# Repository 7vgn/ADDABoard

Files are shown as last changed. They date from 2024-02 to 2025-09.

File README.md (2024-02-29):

# AD/DA Board evolved
## An Add-On for the ATmega644(A) Evaluation Board

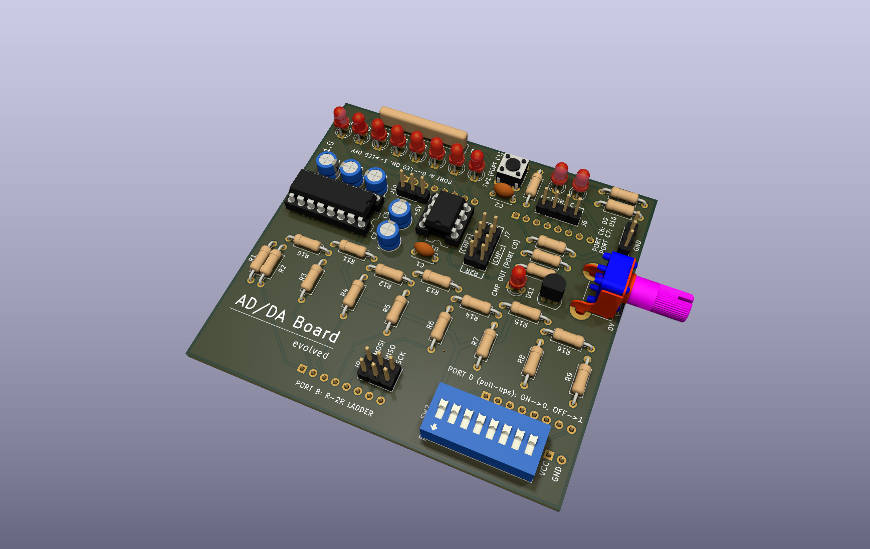
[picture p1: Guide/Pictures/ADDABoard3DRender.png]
3D render of the add-on board


This is an add-on for the [EvaBoard evolved](https://github.com/7vgn/EvaBoard/) ATmega644(A) evaluation board. It is inspired by (and compatible with) the add-on board used in the lab course "Praktikum Systemprogrammierung" in the computer science curriculum at RWTH Aachen. It can be used both with the original [evaluation board](https://www.embedded.rwth-aachen.de/doku.php?id=lehre:atmegaevaboard) and its remake. 

This repository contains:

- A richly illustrated [Guide Book](Guide/ADDABoardGuide.pdf) with everything you need to know to build and use the board
- A [KiCAD project](KiCAD/) with the [Schematic](KiCAD/Schematic.pdf) and a PCB layout, ready to be manufactured
- The [bill of materials](BOM/BOM.pdf)
- [Test code](Tests/) for testing and debugging the board

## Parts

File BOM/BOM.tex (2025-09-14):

\documentclass{article}
\usepackage[a4paper, landscape, margin=2.5cm]{geometry}
\usepackage{multirow}
\usepackage{longtable}
\usepackage{textgreek}
\usepackage{hyperref}

\setlength\parindent{0pt}

\begin{document}
\pagestyle{empty}
\section*{AD/DA Board evolved -- Bill of Materials}
Please read the \href{../Guide/ADDABoardGuide.pdf}{guide book} before ordering. 
The table below lists the codes for ordering the components from \href{https://reichelt.de/}{Reichelt}. 
~\\

\begin{center}
\begin{longtable}{|l|l|l|l|l|}
\hline
\textbf{Reference}&\textbf{Part}&\textbf{Value}&\textbf{Quantity}&\textbf{Reichelt\#}\cr\hline
C1, C2&Ceramic Capacitor&100nF&2&X7R-5 100N\cr\hline
C3..C7&Electrolytic Capacitor&1\textmu F, 63V, radial&5&RAD 1/63\footnote{You can also use tantalum capacitors (TANTAL 1,0/35). These are smaller and recommended by the MAX232 datasheet, but more expensive.}\cr\hline
D1..D8&LED&3mm, red&8&LED 3MM RT\cr\hline
D9, D10&LED&3mm, green&2&LED 3MM GN\cr\hline
D11&LED&3mm, yellow&1&LED 3MM GE\cr\hline
J1&Pin socket&2.54mm, 1x2&1&MPE 094-1-002\cr\hline
J2..J5&Pin socket&2.54mm, 1x8&4&MPE 094-1-008\cr\hline
J6, J8, J10&Pin header&2.54mm, 1 row, 10 total&1&SL 1X36G 2,54\cr\hline
J7, J9&Pin header&2.54mm, 2 rows, 7 total&1&SL 2X36G 2,54\cr\hline
Q1&N-FET Transistor&2N7000&1&2N 7000\cr\hline
R1..R9&Resistor&2k\textOmega&9&METALL 2,00K\cr\hline
R10..R16&Resistor&1k\textOmega&7&METALL 1,00K\cr\hline
R17..R19&Resistor&1.5k\textOmega&3&METALL 1,50K\cr\hline
R20&Resistor&10k\textOmega&1&METALL 10,0K\cr\hline
R21&Resistor&330\textOmega&1&METALL 330\cr\hline
R22&Potentiometer\footnote{Optional. You can use an external variable voltage source instead.}&10k\textOmega&1&RK09K111-LIN10K\cr\hline
R23&Resistor&3.3k\textOmega&1&METALL 3,30K\cr\hline
RN1&Resistor network&8x 1.5k\textOmega&1&SIL 9-8 1,5K\cr\hline
SW1&Pushbutton switch&SPST&1&TASTER 9308\cr\hline
\multirow{2}{*}{U1}&Comparator&LM393&1&LM 393 DIP\cr\cline{2-5}
&IC Socket&2x4, 7.62mm&1&GS 8P\cr\hline
\multirow{2}{*}{U2}&RS-232 transceiver\footnote{Optional. You can ``borrow'' the MAX232 from the evaluation board or connect an external voltage source. See \href{../Guide/ADDABoardGuide.pdf}{guide book} for details.}&MAX232&1&TS232CPE\cr\cline{2-5}
&IC Socket&2x8, 7.62mm&1&GS 16P\cr\hline
\end{longtable}
\end{center}

\end{document}

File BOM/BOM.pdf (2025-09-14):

## AD/DA Board evolved – Bill of Materials

Please read the guide book before ordering. The table below lists the codes for ordering the components from Reichelt. (https://reichelt.de/)

Reference | Part | Value | Quantity | Reichelt#
C1, C2 | Ceramic Capacitor | 100nF | 2 | X7R-5 100N
C3..C7 | Electrolytic Capacitor | 1µF, 63V, radial | 5 | RAD 1/63¹
D1..D8 | LED | 3mm, red | 8 | LED 3MM RT
D9, D10 | LED | 3mm, green | 2 | LED 3MM GN
D11 | LED | 3mm, yellow | 1 | LED 3MM GE
J1 | Pin socket | 2.54mm, 1x2 | 1 | MPE 094-1-002
J2..J5 | Pin socket | 2.54mm, 1x8 | 4 | MPE 094-1-008
J6, J8, J10 | Pin header | 2.54mm, 1 row, 10 total | 1 | SL 1X36G 2,54
J7, J9 | Pin header | 2.54mm, 2 rows, 7 total | 1 | SL 2X36G 2,54
Q1 | N-FET Transistor | 2N7000 | 1 | 2N 7000
R1..R9 | Resistor | 2kΩ | 9 | METALL 2,00K
R10..R16 | Resistor | 1kΩ | 7 | METALL 1,00K
R17..R19 | Resistor | 1.5kΩ | 3 | METALL 1,50K
R20 | Resistor | 10kΩ | 1 | METALL 10,0K
R21 | Resistor | 330Ω | 1 | METALL 330
R22 | Potentiometer² | 10kΩ | 1 | RK09K111-LIN10K
R23 | Resistor | 3.3kΩ | 1 | METALL 3,30K
RN1 | Resistor network | 8x 1.5kΩ | 1 | SIL 9-8 1,5K
SW1 | Pushbutton switch | SPST | 1 | TASTER 9308
U1 | Comparator | LM393 | 1 | LM 393 DIP
| IC Socket | 2x4, 7.62mm | 1 | GS 8P
U2 | RS-232 transceiver³ | MAX232 | 1 | TS232CPE
| IC Socket | 2x8, 7.62mm | 1 | GS 16P

1You can also use tantalum capacitors (TANTAL 1,0/35). These are smaller and recommended by the MAX232 datasheet, but more expensive. 2Optional. You can use an external variable voltage source instead.
3Optional. You can “borrow” the MAX232 from the evaluation board or connect an external voltage source. See guide book for details.

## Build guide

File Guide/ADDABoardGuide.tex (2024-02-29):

\documentclass{article}
\usepackage[a4paper]{geometry}
\usepackage[skip=10pt]{parskip}
\usepackage{graphicx}
\usepackage{hyperref}
\usepackage[section]{placeins}
\usepackage[official]{eurosym}
\usepackage{textgreek}
\usepackage{tcolorbox}
\usepackage{listings}
\usepackage{textcomp}
\usepackage{multirow}
\usepackage{tikz}

\setlength\parindent{0pt}

\newenvironment{note}{\begin{tcolorbox}[colback=blue!5!white,colframe=blue!75!black,title=\textbf{Note}]}{\end{tcolorbox}}
\newenvironment{caution}{\begin{tcolorbox}[colback=red!5!white,colframe=red!75!black,title=\textbf{Caution}]}{\end{tcolorbox}}
\newcommand{\datasheet}{\href{https://ww1.microchip.com/downloads/en/DeviceDoc/doc2593.pdf}{datasheet}}
\newcommand{\file}[1]{\texttt{#1}}
\newcommand{\evaboard}{\href{https://github.com/7vgn/EvaBoard/}{evaluation board}}

\lstset
{
	basicstyle=\footnotesize\ttfamily,
	breaklines=true,
	keywordstyle=\bfseries\color{green!40!black},
	commentstyle=\itshape\color{purple!40!black},
	identifierstyle=\color{blue},
	stringstyle=\color{orange},
	tabsize=4
}

\begin{document}
\hypersetup{pageanchor=false}
\begin{titlepage}
\thispagestyle{empty}
\centering
\textsf{\Huge Guide Book}\\[1cm]
\textsf{\Large For the AD/DA Add-On Board}\\[3cm]

\end{titlepage}
\hypersetup{pageanchor=true}

\tableofcontents
\section{Introduction}
This is an add-on for the ATmega644(A) \evaboard. It is inspired by (and compatible with) the \href{https://www.embedded.rwth-aachen.de/doku.php?id=lehre:atmegaevaboard}{add-on board} used in the lab course "Praktikum Systemprogrammierung" in the computer science curriculum at RWTH Aachen. 

The university encourages students and educators to build the evaluation board themselves. However, no resources for the AD/DA add-on board are provided. 

This project is a complete remake of the original add-on board with a focus on low cost and a non-lab environment (no bench supply etc.). It also includes a ton of documentation, especially for students who have not worked with electronics before. 

\begin{note}
Before reading this, you should familiarize yourself with the \evaboard. Many things from its documentation apply here as well and this document can only be considered complete in conjunction with the \href{../../EvaBoard/Guide/EvaBoardGuide.pdf}{evaluation board's Guide Book}.
\end{note}

\subsection{Getting to Know the Add-On Board}\label{sec:boardOverview}
This add-on board carries multiple components that can be used separately or wired together to create an AD converter:
\begin{itemize}
\item A digital-to-analogue (DA) converter in the shape of an R-2R ladder
\item A comparator with multiple power supply options
\item A potentiometer to create analogue voltages
\item 10 LEDs, a button, and an 8-bit DIP switch
\end{itemize}

For more details, refer to the \href{../KiCAD/Schematic.pdf}{schematic}. 

The add-on board plugs into connectors J11..J14 (Port A..D) and J4 (power) of the evaluation board. Table \ref{tab:connections} shows the connections between the ATmega and the add-on components when the add-on board is mounted. 
\begin{table}
\centering
\begin{tabular}{l|l|l}
\textbf{ATmega644}&\textbf{AD/DA add-on board}&\textbf{Remarks}\cr\hline
Pin A0..A7&LEDs 1..8&active low\cr\hline
Pin B0..B7&R-2R ladder&Pin B7 is the MSB\cr\hline
Pin C0&Comparator output&LED11 also shows the comparator output\cr\hline
Pin C1&Button SW1&pull-up on Pin C1 must be enabled\cr\hline
Pin C2..C5&passed through to J6&not usable while JTAG programming\cr\hline
Pin C6, C7&LEDs 9 and 10&active low\cr\hline
Pin D0..D7&8-bit DIP switch&pull-ups on Port D must be enabled\cr\hline
\end{tabular}
\caption{Connections between the Add-On Board and the Evaluation Board}
\label{tab:connections}
\end{table}

\subsubsection{R-2R Ladder}
An \href{https://en.wikipedia.org/wiki/Resistor_ladder}{R-2R ladder} is a simple circuit that converts a digital value to an analogue voltage using a network of resistors with two different values, one twice as large as the other (1k\textOmega{} and 2k\textOmega{} in our case). 
The R-2R ladder is connected to Port B in such a way that a digital value written to the 8-bit PORTB register is translated proportionally to a voltage between 0V and 5V. The output voltage is available on two pins of J7. 

\begin{note}
Pins 5..7 of Port B are also used for ISP programming. The R-2R ladder will act as a pull-down resistor on these pins. Decent ISP programmers should not have an issue with this. If you encounter difficulties, remove the add-on board while programming or cut the solder jumpers JP1..JP3. You can reconnect these pins to the R-2R ladder by placing jumpers on J9. 
\end{note}

\subsubsection{Comparator}\label{sec:cmp}
The \href{https://www.ti.com/lit/ds/symlink/lm393.pdf}{LM393} is a very common dual comparator. On this board, only one of the two comparators is in use. The comparator has two inputs \texttt{IN+} and \texttt{IN-} and one output. The output is high (logic 1) whenever the voltage at \texttt{IN+} is greater than the voltage at \texttt{IN-}, and low (logic 0) whenever the opposite is the case. The two inputs are available at the middle pins of J7. The output is connected to Port C0 as well as LED11 (``CMP OUT''). 

Figure \ref{fig:cmpSchematic} shows the schematic symbol of a comparator. It resembles that of an operational amplifier. This is not a coincidence: OpAmps can be used as comparators (with mediocre performance). 

\begin{figure}[htb]
\centering
\begin{tikzpicture}
\node[circle,fill,minimum size=6pt,inner sep=0,outer sep=0,label=left:IN+] (INP) at (-1,1) {};
\node[circle,fill,minimum size=6pt,inner sep=0,outer sep=0,label=left:IN-] (INM) at (-1,-1) {};
\node[circle,fill,minimum size=6pt,inner sep=0,outer sep=0,label=right:OUT] (OUT) at (5,0) {};
\node[circle,fill,minimum size=6pt,inner sep=0,outer sep=0,label=right:V+] (VP) at (2,2) {};
\node[circle,fill,minimum size=6pt,inner sep=0,outer sep=0,label=right:V- (GND)] (VM) at (2,-2) {};

\filldraw[fill=yellow!50!white] (0,2) -- (0,-2) -- (4,0) -- cycle;
\draw (INP) -- (0,1);
\draw (INM) -- (0,-1);
\draw (4,0) -- (OUT);
\draw (VP) -- (2,1);
\draw (VM) -- (2,-1);
\end{tikzpicture}
\caption{Comparator Schematic}
\label{fig:cmpSchematic}
\end{figure}

The comparator needs a supply voltage which has to be at least 2V higher than the \texttt{IN+} and \texttt{IN-} voltages (see Section 6.2 in the \href{https://www.ti.com/lit/ds/symlink/lm393.pdf}{datasheet}). Since we want to compare voltages in the 0V..5V range, the comparator must be supplied with at least 7V which is not immediately available on the evaluation board. There are three options:

\begin{itemize}
\item Provide an external supply voltage $\ge$7V between V+ (the middle pin of J10) and GND (J8). Depending on the quality of the external supply, this can be the most stable solution and provide the most accurate results. 
\item Use 5V as the power supply by connecting the middle and bottom pin of J10 with a jumper. This limits the usable range of the comparator to 0V..3V!
\item Create a higher voltage from 5V. Fortunately, the comparator does not draw a lot of current. Thus we can (ab)use a MAX232 driver which creates a voltage somewhere between 8V and 9V, depending on current. You don't even need to buy a MAX232 -- you can pinch the one from the evaluation board, unless you want to use the serial connection and the AD/DA add-on board at the same time. Insert the MAX232 into the U2 socket of the add-on board and connect the middle and top pin of J10 with a jumper. 
\end{itemize}

The third option is recommended since it is cheap while still delivering good results. Figure \ref{fig:cmpSupplyOptions} shows the role of J10 in choosing the comparator supply voltage. 
\begin{figure}[htb]
\centering
\begin{tikzpicture}
\node[circle,fill,minimum size=6pt,inner sep=0,outer sep=0,label=left:8..9V from MAX232] (MAX) at (0,3) {};
\node[circle,fill,minimum size=6pt,inner sep=0,outer sep=0,label=left:$\ge$7V external voltage] (EXT) at (0,2) {};
\node[circle,fill,minimum size=6pt,inner sep=0,outer sep=0,label=left:5V from VCC] (VCC) at (0,1) {};
\node[circle,fill,minimum size=6pt,inner sep=0,outer sep=0,label=right:V+ comparator supply] (VP) at (6,2) {};

\draw (2,0) rectangle (4,4);
\node[anchor=north west] at (4,0) {J10};
\node[circle,fill,minimum size=6pt,inner sep=0,outer sep=0,label=above right:1] (J1) at (3,1) {};
\node[circle,fill,minimum size=6pt,inner sep=0,outer sep=0,label=above right:2] (J2) at (3,2) {};
\node[circle,fill,minimum size=6pt,inner sep=0,outer sep=0,label=above right:3] (J3) at (3,3) {};

\draw (MAX) -- (J3);
\draw (VCC) -- (J1);
\draw[dashed] (EXT) -- (J2);
\draw (J2) -- (VP);

\draw[draw=blue] (2.45,0.5) rectangle (3.45,2.5);
\draw[draw=green!70!black] (2.55,1.5) rectangle (3.55,3.5);
\end{tikzpicture}
\caption{Comparator Supply Voltage Options}
\label{fig:cmpSupplyOptions}
\end{figure}

\subsubsection{Potentiometer}\label{sec:poti}
Since the whole purpose of an AD converter is to measure some analogue voltage, we need a way of generating one. The potentiometer R22 acts as a variable voltage divider between 5V and GND. When turned all the way to the left, its output is 0V, to the right it's 5V. The potentiometer output is available on two pins of J7. If you have a variable external voltage source available, you can of course omit R22. 

\subsection{Changes from the Original Board}\label{sec:differences}
No schematic is published for the original AD/DA board. Figure \ref{fig:addaOrig} is our best guess of what it looks like. 

\begin{figure}[htb]
\centering

\caption{Schematic of the Original AD/DA Add-on Board (guesswork)}
\label{fig:addaOrig}
\end{figure}

The main difference is the use of the LM393 comparator instead of an LM358 OpAmp and its power supply. Re-using the MAX232 instead of two additional voltage regulators lowers the cost of this board significantly. 

\section{Building the Board}
Please read the corresponding chapter in the evaluation board's \href{https://github.com/7vgn/EvaBoard/Guide/EvaBoardGuide.pdf}{guide book}. Assembling the add-on board should not pose any additional difficulties. 

\begin{note}
The best technique for soldering the pin sockets J1..J5 onto the back of the PCB is to attach them to the (unpowered!) evaluation board, then place the add-on PCB on top and solder all pins. This way, the add-on board will fit perfectly onto the evaluation board. 
\end{note}

\begin{caution}
Make sure to cut all the components' legs short enough so they won't touch anything on the evaluation board. To be safe, cover the back of the add-on board with tape. 
\end{caution}

\subsection{Optional Components}
The potentiometer R22 can be omitted in favour of an external variable voltage source, see Section \ref{sec:poti}. 

If the ATmega is programmed exclusively via JTAG, J6 is unnecessary since those pins aren't usable anyway. 

J9 can be left unpopulated unless you need to cut the solder jumpers JP1..3 due to problems with ISP programming while the R-2R ladder is connected to Port B. 

The IC socket for U2 as well as C3..C7 can be omitted if you are providing the comparator with a different supply voltage, see Section \ref{sec:cmp}. 

If you are using tantalum capacitors for C3..C7, make sure to get the polarity correct. Unfortunately, the markings are not uniform. The plus side might be marked by a plus sign, a line, a dot, or a longer leg. If there is text printed on it, the plus side is usually on the right. If in doubt, \href{https://en.wikipedia.org/wiki/Tantalum_capacitor#Polarity_marking}{read up} on it before soldering -- with the wrong polarity tantalum capacitors can explode!

\section{Testing}
The test programs can be found in the \href{../Tests/}{\file{Tests/} subdirectory} of this repository. They all come with makefiles for AVR-GCC and AVRDUDE. Alternatively, you can create a project in your IDE of choice and import the source files there. Be sure to define the \lstinline[language=C]{F_CPU} constant if your IDE doesn't do that automatically.

\subsection{DIP switches and LEDs}
The code for this test can be found in \href{../Tests/DIPLED/}{\file{Tests/DIPLED/}}. 

\paragraph{Preparation}
Plug the AD/DA add-on board onto the evaluation board. 

\paragraph{Expected Result}
Whenever a DIP switch is activated, the corresponding LED should light up. Pressing the SW1 should switch between LED9 and LED10. 

\begin{figure}[htb]
\centering
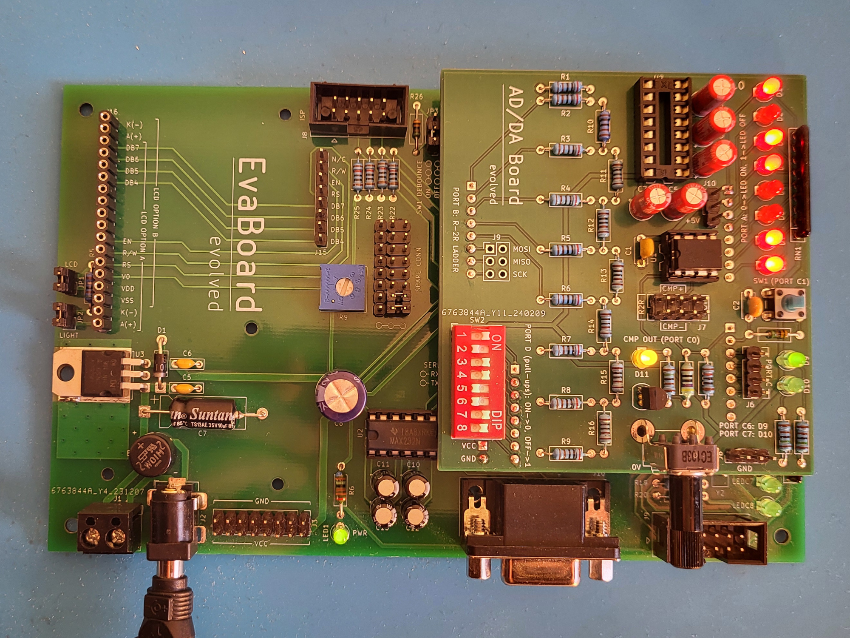
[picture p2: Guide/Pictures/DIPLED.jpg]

\caption{Setup for Testing the DIP Switches and LEDs}
\label{fig:dipLed}
\end{figure}

\paragraph{Troubleshooting}
Make sure the evaluation board works reliably. After that, any failure on this simple test is probably due to bad soldering or an LED being placed the wrong way. 

\subsection{R-2R Ladder}
The code for this test can be found in \href{../Tests/R2R/}{\file{Tests/R2R/}}. This test requires a somewhat accurate multimeter. 

\paragraph{Preparation}
Plug the AD/DA add-on board onto the evaluation board. 

\paragraph{Expected Result}
Enter a value $v\in\{0,\ldots,255\}$ in binary via the DIP switches. It should be echoed on the LEDs. Measure the voltage $U$ between the R2R pins on J7 and GND (J8). You should get approximately the following relation:
\[
U=5V\cdot\frac{v}{255}
\]
For a more precise result, measure the supply voltage (pin marked ``+5V'' on J10) and replace the ``5V'' in the equation with that value. 

\paragraph{Troubleshooting}
If the observed values deviate significantly from the expected ones, check if you have chosen the correct values for all resistors. You might also have a bad solder joint on one of the resistors, adding a few ohms. 

\begin{note}
When one of the ATmega's output pins is set to logic 1, its voltage does not quite reach VCC\footnote{The \href{https://ww1.microchip.com/downloads/en/DeviceDoc/doc2593.pdf}{datasheet} guarantees 4.2V, see Section 26.2. The exact value depends on the current sourced from the pin, see Figure 27-31.}. Therefore, the observed values will probably all have a slight downward bias. 
\end{note}

\subsection{A Primitive AD converter}
The code for this test can be found in \href{../Tests/ADC/}{\file{Tests/ADC/}}. 

\paragraph{Preparation}
Plug the AD/DA add-on board onto the evaluation board. Connect R-2R to CMP+ and POT to CMP- by placing two jumpers on J7. 
Use one of the methods from Section \ref{sec:cmp} to supply the comparator with voltage. 

\begin{figure}[htb]
\centering
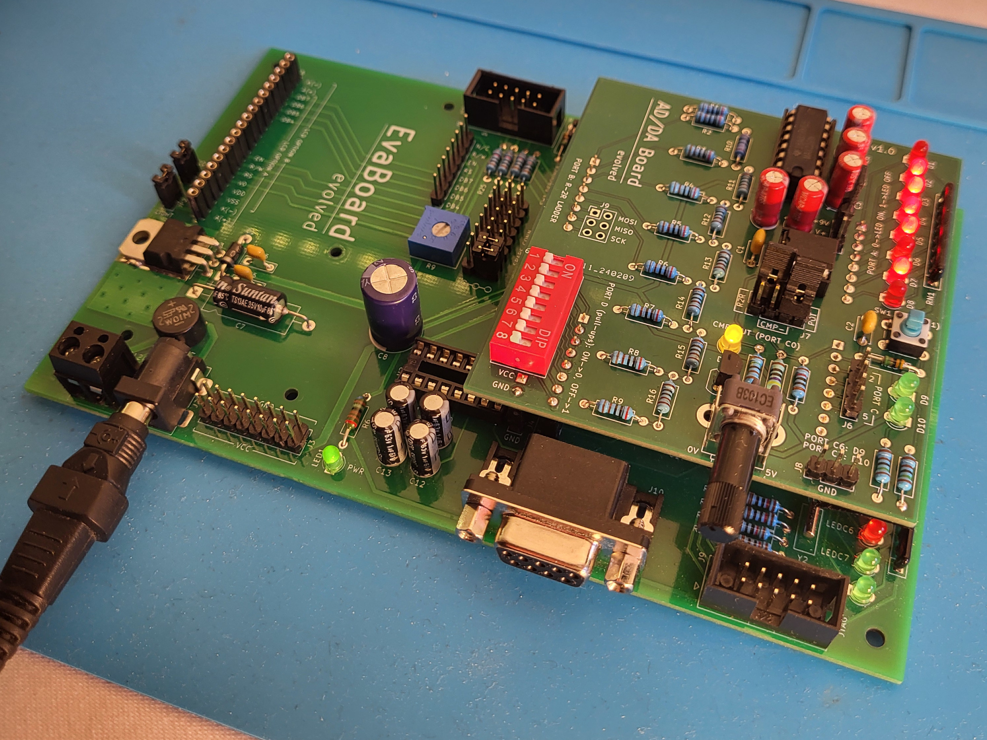
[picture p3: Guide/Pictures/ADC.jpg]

\caption{Setup for a Simple AD Converter (Using MAX232 for Supplying the Comparator)}
\label{fig:adc}
\end{figure}

\paragraph{Expected Result}
Select a voltage with the potentionmeter. Press the RESET button or disconnect and re-connect the power or reset the microcontroller via the programmer. 

The LEDs should show an increasing binary value which stops when the corresponding voltage from the R-2R ladder exceeds the potentiometer voltage. This is indicated by the ``CMP OUT'' LED lighting up. 

\begin{note}
This is a very primitive and slow ADC. You might view it as a linear search for the value where the comparator first outputs 1. You can improve it massively by using a more sophisticated search algorithm. 
\end{note}

\section{Known Issues}
In theory, the LEDs 1..10 and SW1 are superfluous. One could save on parts and use the LEDs and buttons on the evaluation board instead. However, this would require the PCB to be non-rectangular, probably offsetting any savings. 

\section{Version History}
\begin{description}
\item[v1.0] Initial release
\end{description}

\end{document}

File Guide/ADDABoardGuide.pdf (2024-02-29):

# Guide Book

## For the AD/DA Add-On Board


## Contents

1 Introduction | 1
2 Building the Board | 4
3 Testing | 5
4 Known Issues | 8
5 Version History | 8

## 1 Introduction

This is an add-on for the ATmega644(A) evaluation board. (https://github.com/jdcr0/EvaBoard/) It is inspired by (and compatible with) the add-on board (https://www.embedded.rwth-aachen.de/doku.php?id=lehre:atmegaevaboard) used in the lab course ”Praktikum Systemprogrammierung” in the computer science curriculum at RWTH Aachen.

The university encourages students and educators to build the evaluation board themselves. However, no resources for the AD/DA add-on board are provided.

This project is a complete remake of the original add-on board with a focus on low cost and a non-lab environment (no bench supply etc.). It also includes a ton of documentation, especially for students who have not worked with electronics before.

Note

Before reading this, you should familiarize yourself with the evaluation board. (https://github.com/jdcr0/EvaBoard/) Many things from its documentation apply here as well and this document can only be considered complete in conjunction with the evaluation board’s Guide Book.

### 1.1 Getting to Know the Add-On Board

This add-on board carries multiple components that can be used separately or wired together to create an AD converter:

- A digital-to-analogue (DA) converter in the shape of an R-2R ladder
- A comparator with multiple power supply options
- A potentiometer to create analogue voltages

1

ATmega644 | AD/DA add-on board | Remarks
Pin A0..A7 | LEDs 1..8 | active low
Pin B0..B7 | R-2R ladder | Pin B7 is the MSB
Pin C0 | Comparator output | LED11 also shows the comparator output
Pin C1 | Button SW1 | pull-up on Pin C1 must be enabled
Pin C2..C5 | passed through to J6 | not usable while JTAG programming
Pin C6, C7 | LEDs 9 and 10 | active low
Pin D0..D7 | 8-bit DIP switch | pull-ups on Port D must be enabled

Table 1: Connections between the Add-On Board and the Evaluation Board

- 10 LEDs, a button, and an 8-bit DIP switch

For more details, refer to the schematic.

The add-on board plugs into connectors J11..J14 (Port A..D) and J4 (power) of the evaluation board. Table 1 shows the connections between the ATmega and the add-on components when the add-on board is mounted.

### 1.1.1 R-2R Ladder

An R-2R ladder (https://en.wikipedia.org/wiki/Resistor_ladder) is a simple circuit that converts a digital value to an analogue voltage using a network of resistors with two different values, one twice as large as the other (1kΩ and 2kΩ in our case). The R-2R ladder is connected to Port B in such a way that a digital value written to the 8-bit PORTB register is translated proportionally to a voltage between 0V and 5V. The output voltage is available on two pins of J7.

Note

Pins 5..7 of Port B are also used for ISP programming. The R-2R ladder will act as a pull-down resistor on these pins. Decent ISP programmers should not have an issue with this. If you encounter difficulties, remove the add-on board while programming or cut the solder jumpers JP1..JP3. You can reconnect these pins to the R-2R ladder by placing jumpers on J9.

### 1.1.2 Comparator

The LM393 (https://www.ti.com/lit/ds/symlink/lm393.pdf) is a very common dual comparator. On this board, only one of the two comparators is in use. The comparator has two inputs IN+ and IN- and one output. The output is high (logic
1) whenever the voltage at IN+ is greater than the voltage at IN-, and low (logic 0) whenever the opposite is the case. The two inputs are available at the middle pins of J7. The output is connected to Port C0 as well as LED11 (“CMP OUT”).

Figure 1 shows the schematic symbol of a comparator. It resembles that of an operational amplifier. This is not a coincidence: OpAmps can be used as comparators (with mediocre performance).

The comparator needs a supply voltage which has to be at least 2V higher than the IN+ and IN-voltages (see Section 6.2 in the datasheet). (https://www.ti.com/lit/ds/symlink/lm393.pdf) Since we want to compare voltages in the 0V..5V

2

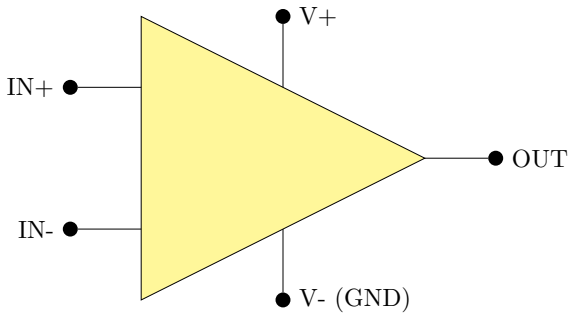
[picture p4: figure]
OUT; V- (GND)

Figure 1: Comparator Schematic

range, the comparator must be supplied with at least 7V which is not immediately available on the evaluation board. There are three options:

- Provide an external supply voltage ≥7V between V+ (the middle pin of J10) and GND (J8). Depending on the quality of the external supply, this can be the most stable solution and provide the most accurate results.
- Use 5V as the power supply by connecting the middle and bottom pin of J10 with a jumper. This limits the usable range of the comparator to 0V..3V!
- Create a higher voltage from 5V. Fortunately, the comparator does not draw a lot of current. Thus we can (ab)use a MAX232 driver which creates a voltage somewhere between 8V and 9V, depending on current. You don’t even need to buy a MAX232 – you can pinch the one from the evaluation board, unless you want to use the serial connection and the AD/DA add-on board at the same time. Insert the MAX232 into the U2 socket of the add-on board and connect the middle and top pin of J10 with a jumper.

The third option is recommended since it is cheap while still delivering good results. Figure 2 shows the role of J10 in choosing the comparator supply voltage.

8..9V from MAX232

≥7V external voltage

5V from VCC

V+ comparator supply

J10

1

2

3

Figure 2: Comparator Supply Voltage Options

3

### 1.1.3 Potentiometer

Since the whole purpose of an AD converter is to measure some analogue voltage, we need a way of generating one. The potentiometer R22 acts as a variable voltage divider between 5V and GND. When turned all the way to the left, its output is 0V, to the right it’s 5V. The potentiometer output is available on two pins of J7. If you have a variable external voltage source available, you can of course omit R22.

### 1.2 Changes from the Original Board

No schematic is published for the original AD/DA board. Figure 3 is our best guess of what it

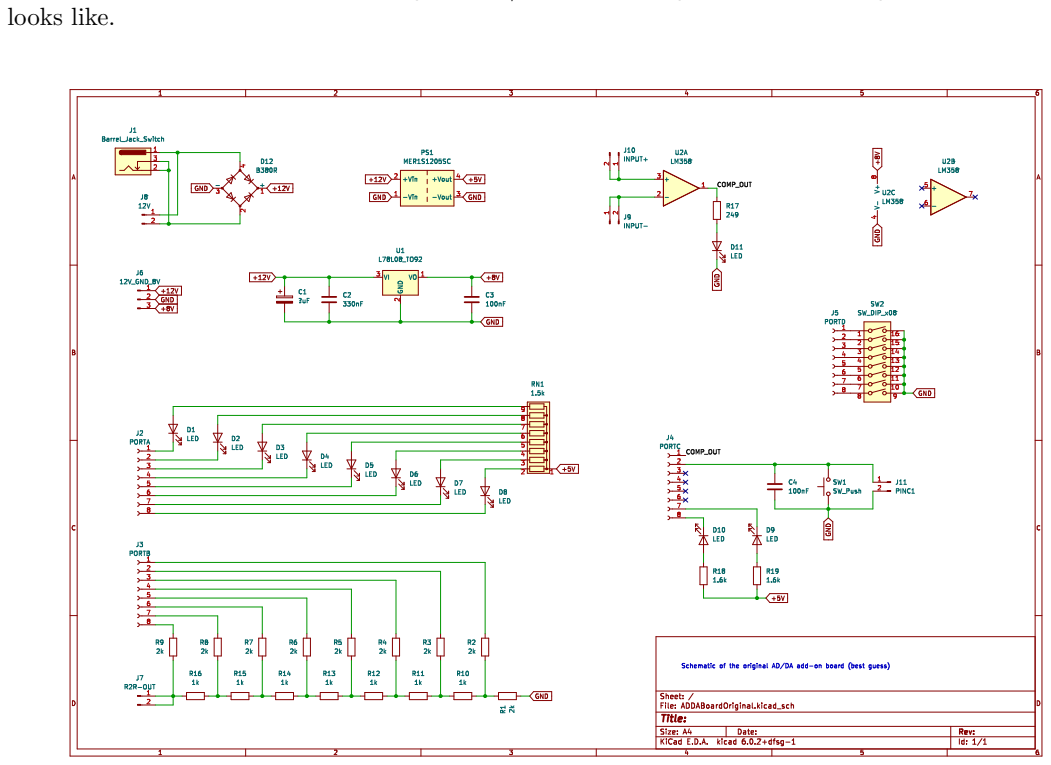
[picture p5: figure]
looks like.

Figure 3: Schematic of the Original AD/DA Add-on Board (guesswork)

The main difference is the use of the LM393 comparator instead of an LM358 OpAmp and its power supply. Re-using the MAX232 instead of two additional voltage regulators lowers the cost of this board significantly.

## 2 Building the Board

Please read the corresponding chapter in the evaluation board’s guide book. (https://github.com/jdcr0/EvaBoard/Guide/EvaBoardGuide.pdf) Assembling the add-on board should not pose any additional difficulties.

4

Note

The best technique for soldering the pin sockets J1..J5 onto the back of the PCB is to attach them to the (unpowered!) evaluation board, then place the add-on PCB on top and solder all pins. This way, the add-on board will fit perfectly onto the evaluation board.

Caution

Make sure to cut all the components’ legs short enough so they won’t touch anything on the evaluation board. To be safe, cover the back of the add-on board with tape.

### 2.1 Optional Components

The potentiometer R22 can be omitted in favour of an external variable voltage source, see Section 1.1.3.

If the ATmega is programmed exclusively via JTAG, J6 is unnecessary since those pins aren’t usable anyway.

J9 can be left unpopulated unless you need to cut the solder jumpers JP1..3 due to problems with ISP programming while the R-2R ladder is connected to Port B.

The IC socket for U2 as well as C3..C7 can be omitted if you are providing the comparator with a different supply voltage, see Section 1.1.2.

If you are using tantalum capacitors for C3..C7, make sure to get the polarity correct. Unfor-tunately, the markings are not uniform. The plus side might be marked by a plus sign, a line, a dot, or a longer leg. If there is text printed on it, the plus side is usually on the right. If in doubt, read up (https://en.wikipedia.org/wiki/Tantalum_capacitor#Polarity_marking) on it before soldering – with the wrong polarity tantalum capacitors can explode!

## 3 Testing

The test programs can be found in the Tests/ subdirectory of this repository. They all come with makefiles for AVR-GCC and AVRDUDE. Alternatively, you can create a project in your IDE of choice and import the source files there. Be sure to define the F_CPU constant if your IDE doesn’t do that automatically.

### 3.1 DIP switches and LEDs

The code for this test can be found in Tests/DIPLED/.

Preparation Plug the AD/DA add-on board onto the evaluation board.

Expected Result Whenever a DIP switch is activated, the corresponding LED should light up. Pressing the SW1 should switch between LED9 and LED10.

5


Figure 4: Setup for Testing the DIP Switches and LEDs

Troubleshooting Make sure the evaluation board works reliably. After that, any failure on this simple test is probably due to bad soldering or an LED being placed the wrong way.

### 3.2 R-2R Ladder

The code for this test can be found in Tests/R2R/. This test requires a somewhat accurate multimeter.

Preparation Plug the AD/DA add-on board onto the evaluation board.

Expected Result Enter a value v ∈ {0, . . . , 255} in binary via the DIP switches. It should be echoed on the LEDs. Measure the voltage U between the R2R pins on J7 and GND (J8). You should get approximately the following relation:

U = 5V ·

v
255

For a more precise result, measure the supply voltage (pin marked “+5V” on J10) and replace the “5V” in the equation with that value.

Troubleshooting If the observed values deviate significantly from the expected ones, check if you have chosen the correct values for all resistors. You might also have a bad solder joint on one of the resistors, adding a few ohms.

6

Note

When one of the ATmega’s output pins is set to logic 1, its voltage does not quite reach VCCa
. Therefore, the observed values will probably all have a slight downward bias.

aThe datasheet (https://ww1.microchip.com/downloads/en/DeviceDoc/doc2593.pdf) guarantees 4.2V, see Section 26.2. The exact value depends on the current sourced from the pin, see Figure 27-31.

### 3.3 A Primitive AD converter

The code for this test can be found in Tests/ADC/.

Preparation Plug the AD/DA add-on board onto the evaluation board. Connect R-2R to CMP+ and POT to CMP- by placing two jumpers on J7. Use one of the methods from Section 1.1.2 to supply the comparator with voltage.


Figure 5: Setup for a Simple AD Converter (Using MAX232 for Supplying the Comparator)

Expected Result Select a voltage with the potentionmeter. Press the RESET button or disconnect and re-connect the power or reset the microcontroller via the programmer.

The LEDs should show an increasing binary value which stops when the corresponding voltage from the R-2R ladder exceeds the potentiometer voltage. This is indicated by the “CMP OUT” LED lighting up.

7

Note

This is a very primitive and slow ADC. You might view it as a linear search for the value where the comparator first outputs 1. You can improve it massively by using a more sophisticated search algorithm.

## 4 Known Issues

In theory, the LEDs 1..10 and SW1 are superfluous. One could save on parts and use the LEDs and buttons on the evaluation board instead. However, this would require the PCB to be non-rectangular, probably offsetting any savings.

## 5 Version History

v1.0 Initial release

8

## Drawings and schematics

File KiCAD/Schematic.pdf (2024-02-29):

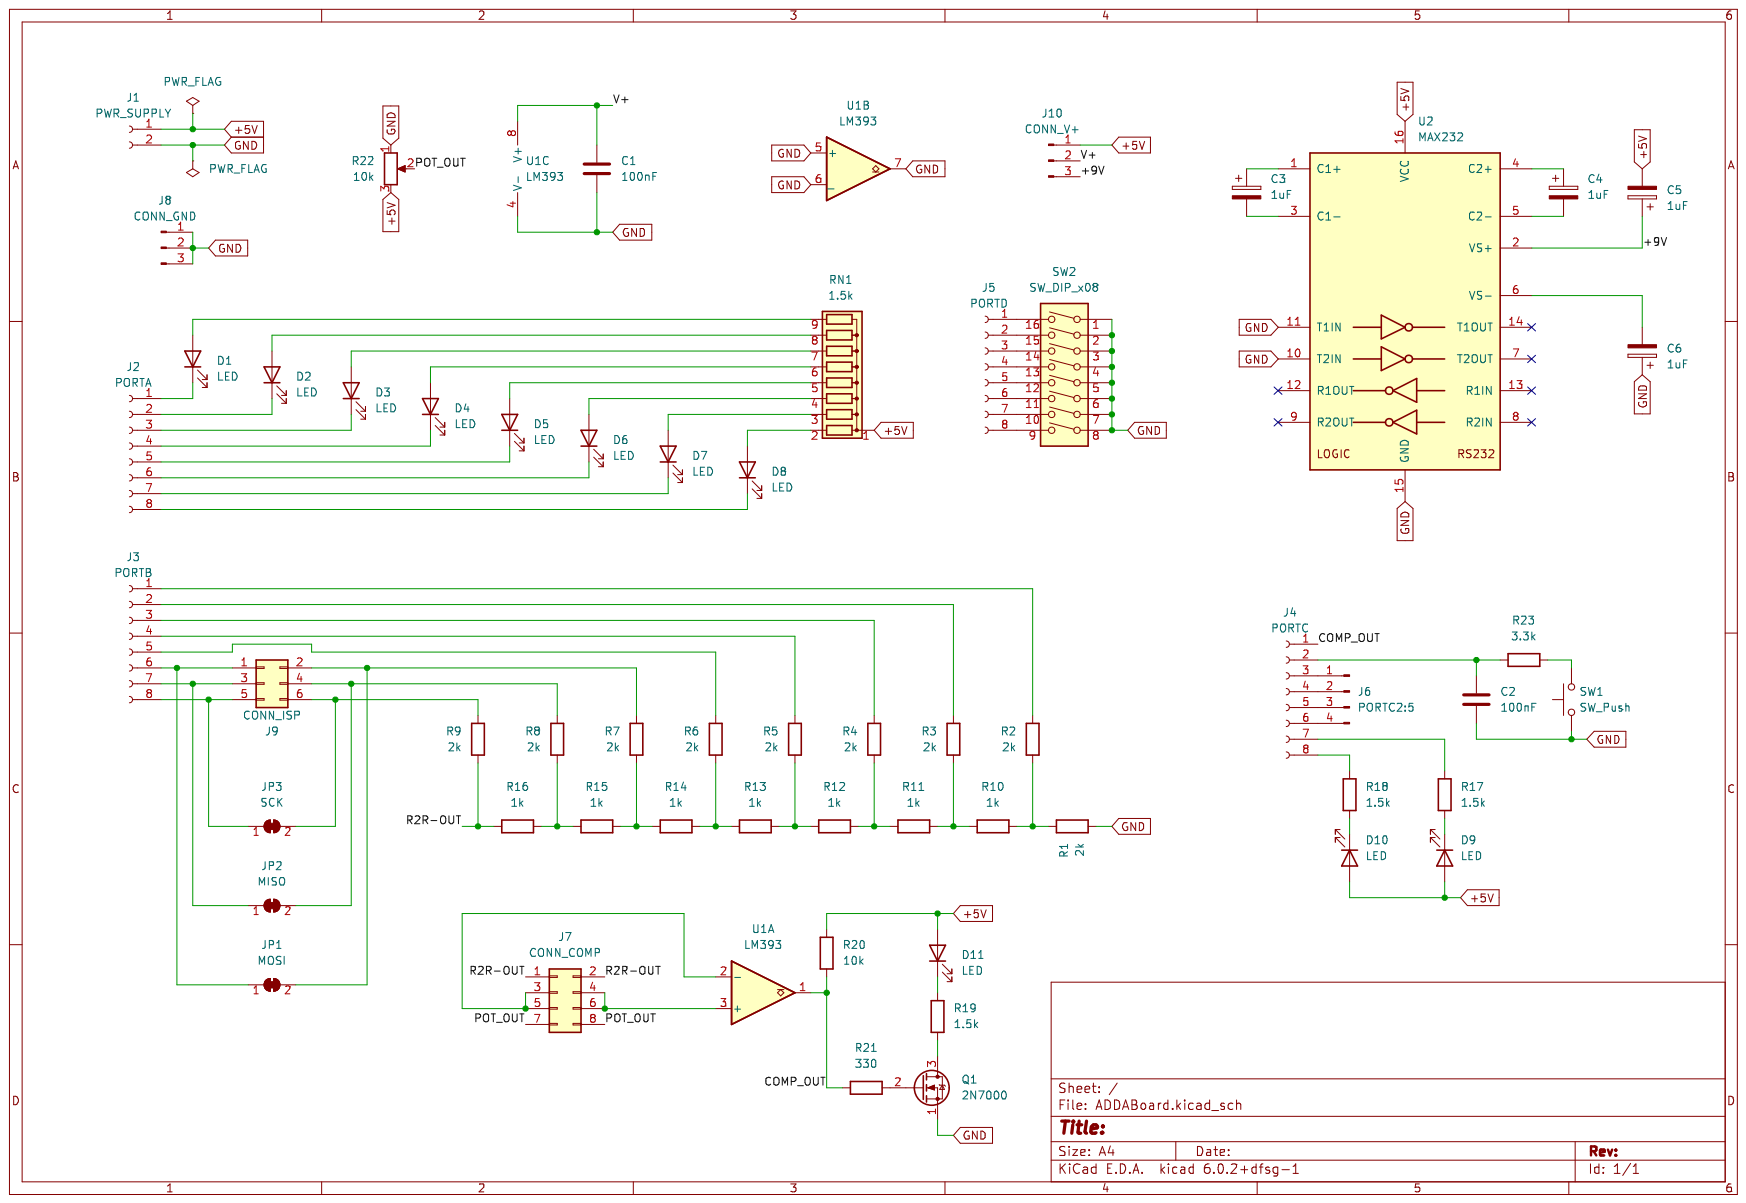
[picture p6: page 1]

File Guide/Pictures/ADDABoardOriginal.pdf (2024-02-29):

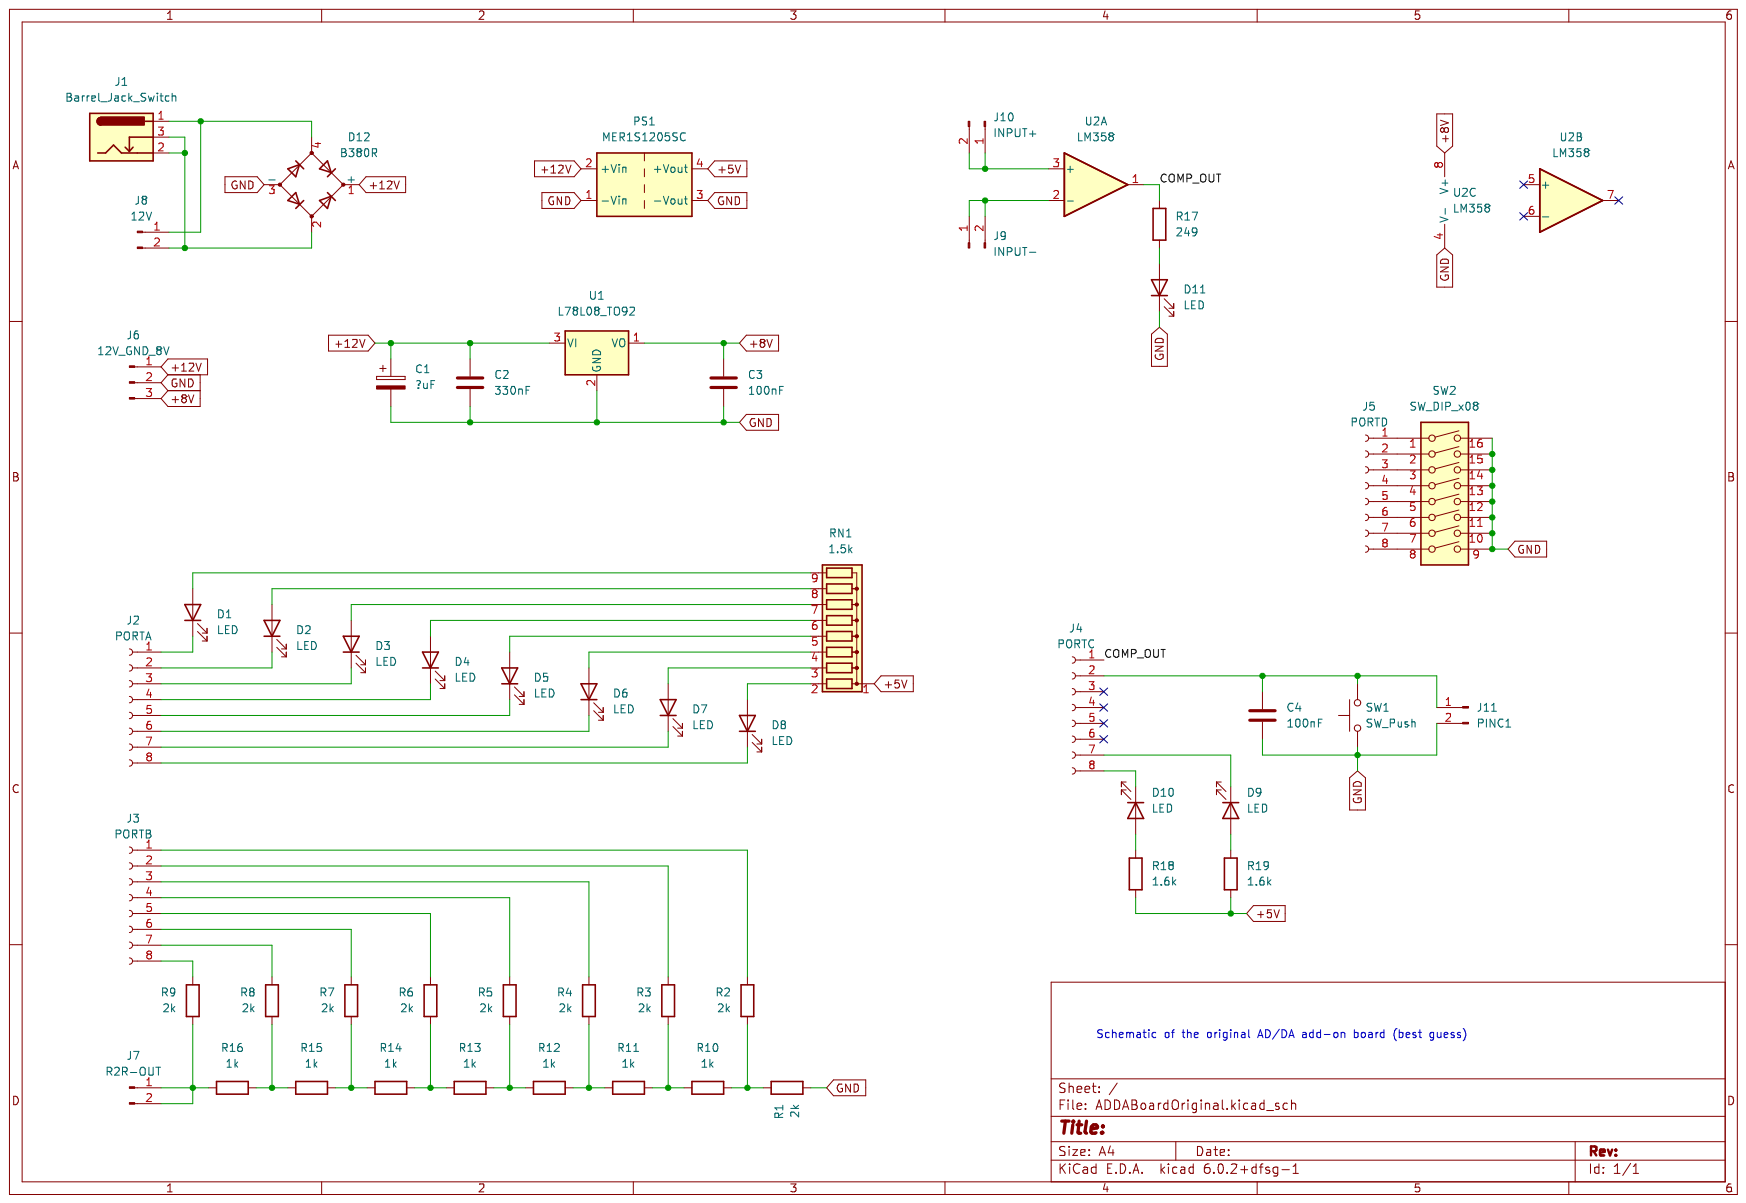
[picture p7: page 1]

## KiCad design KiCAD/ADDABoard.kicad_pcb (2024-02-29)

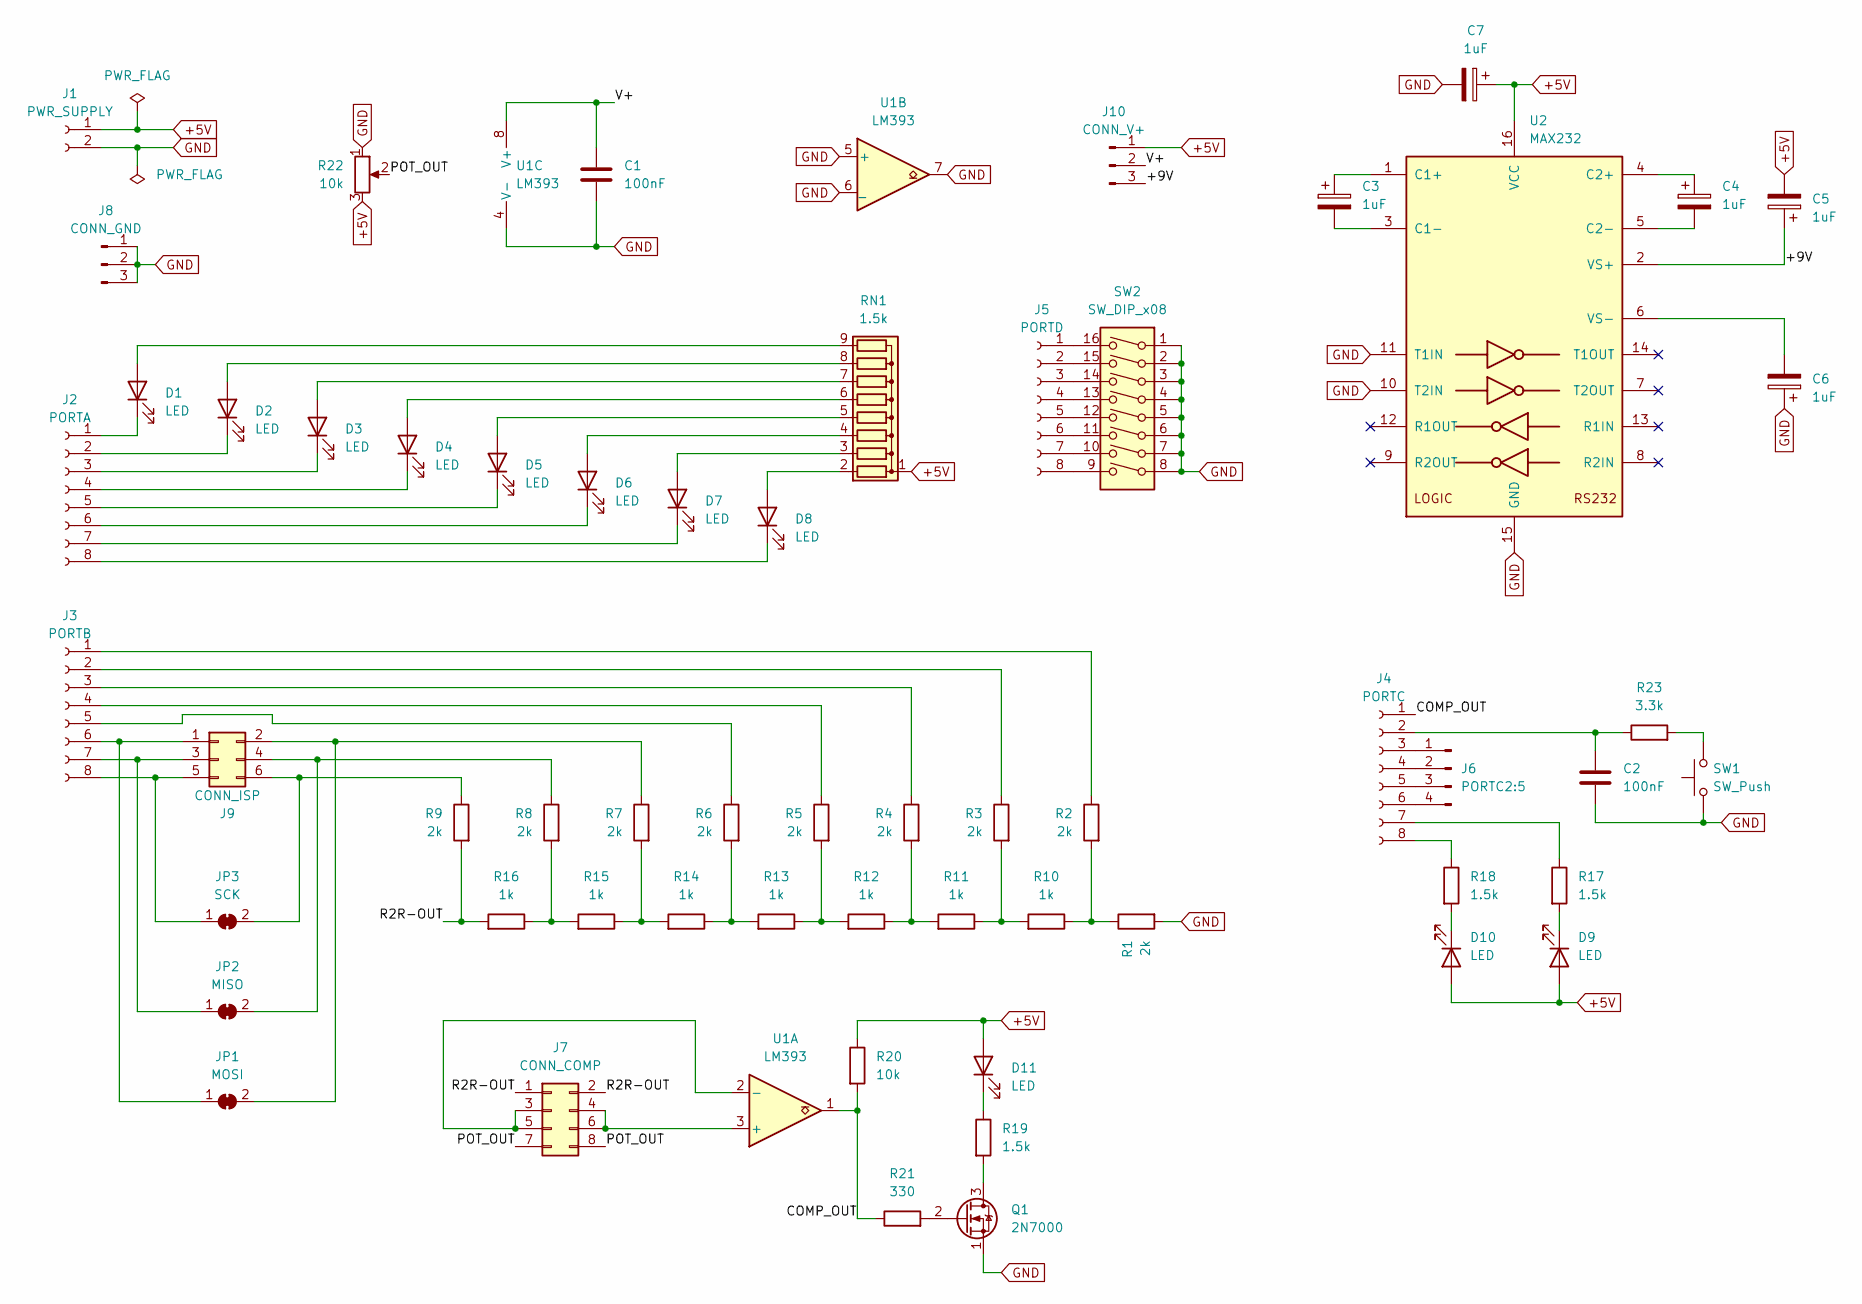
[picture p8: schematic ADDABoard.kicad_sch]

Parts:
C1, C2: 100nF; C_Disc_D5.0mm_W2.5mm_P5.00mm
C3, C4, C5, C6, C7: 1uF; CP_Radial_D5.0mm_P2.00mm
D1, D2, D3, D4, D5, D6, D7, D8, D9, D10, D11: LED; LED_D3.0mm
J1: PWR_SUPPLY; PinSocket_1x02_P2.54mm_Vertical
J2: PORTA; PinSocket_1x08_P2.54mm_Vertical
J3: PORTB; PinSocket_1x08_P2.54mm_Vertical
J4: PORTC; PinSocket_1x08_P2.54mm_Vertical
J5: PORTD; PinSocket_1x08_P2.54mm_Vertical
J6: PORTC2:5; PinHeader_1x04_P2.54mm_Vertical
J7: CONN_COMP; PinHeader_2x04_P2.54mm_Vertical
J8: CONN_GND; PinHeader_1x03_P2.54mm_Vertical
J9: CONN_ISP; PinHeader_2x03_P2.54mm_Vertical
J10: CONN_V+; PinHeader_1x03_P2.54mm_Vertical
JP1: MOSI; SolderJumper-2_P1.3mm_Bridged_RoundedPad1.0x1.5mm
JP2: MISO; SolderJumper-2_P1.3mm_Bridged_RoundedPad1.0x1.5mm
JP3: SCK; SolderJumper-2_P1.3mm_Bridged_RoundedPad1.0x1.5mm
Q1: 2N7000; TO-92_Inline
R1, R2, R3, R4, R5, R6, R7, R8, R9: 2k; R_Axial_DIN0207_L6.3mm_D2.5mm_P10.16mm_Horizontal
R10, R11, R12, R13, R14, R15, R16: 1k; R_Axial_DIN0207_L6.3mm_D2.5mm_P10.16mm_Horizontal
R17, R18, R19: 1.5k; R_Axial_DIN0207_L6.3mm_D2.5mm_P10.16mm_Horizontal
R20: 10k; R_Axial_DIN0207_L6.3mm_D2.5mm_P10.16mm_Horizontal
R21: 330; R_Axial_DIN0207_L6.3mm_D2.5mm_P10.16mm_Horizontal
R22: 10k; Potentiometer_Alps_RK09K_Single_Horizontal
R23: 3.3k; R_Axial_DIN0207_L6.3mm_D2.5mm_P10.16mm_Horizontal
RN1: 1.5k; R_Array_SIP9
SW1: SW_Push; SW_PUSH_6mm
SW2: SW_DIP_x08; SW_DIP_SPSTx08_Slide_9.78x22.5mm_W7.62mm_P2.54mm
U1: LM393; DIP-8_W7.62mm
U2: MAX232; DIP-16_W7.62mm

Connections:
+5V: C5.2, C7.1, D9.2 (A), D10.2 (A), D11.2 (A), J1.1, J10.1, R20.1, R22.3, RN1.1 (common), U2.16 (VCC)
/+9V: C5.1, J10.3, U2.2 (VS+)
/COMP_OUT: J4.1, R20.2, R21.1, U1.1
/POT_OUT: J7.7, J7.8, R22.2
/R2R-OUT: J7.1, J7.2, R9.2, R16.2
/V+: C1.1, J10.2, U1.8 (V+)
GND: C1.2, C2.2, C6.1, C7.2, J1.2, J8.1, J8.2, J8.3, Q1.1 (S), R1.2, R22.1, SW1.1, SW2.1, SW2.2, SW2.3, SW2.4, SW2.5, SW2.6, SW2.7, SW2.8, U1.4 (V-), U1.5 (+), U1.6 (_), U1.7, U2.10 (T2IN), U2.11 (T1IN), U2.15 (GND)
unnamed: C2.1, J4.2, R23.1
unnamed: C3.1, U2.1 (C1+)
unnamed: C3.2, U2.3 (C1-)
unnamed: C4.1, U2.4 (C2+)
unnamed: C4.2, U2.5 (C2-)
unnamed: C6.2, U2.6 (VS-)
unnamed: D1.1 (K), J2.1
unnamed: D1.2 (A), RN1.9 (R8)
unnamed: D2.1 (K), J2.2
unnamed: D2.2 (A), RN1.8 (R7)
unnamed: D3.1 (K), J2.3
unnamed: D3.2 (A), RN1.7 (R6)
unnamed: D4.1 (K), J2.4
unnamed: D4.2 (A), RN1.6 (R5)
unnamed: D5.1 (K), J2.5
unnamed: D5.2 (A), RN1.5 (R4)
unnamed: D6.1 (K), J2.6
unnamed: D6.2 (A), RN1.4 (R3)
unnamed: D7.1 (K), J2.7
unnamed: D7.2 (A), RN1.3 (R2)
unnamed: D8.1 (K), J2.8
unnamed: D8.2 (A), RN1.2 (R1)
unnamed: D9.1 (K), R17.2
unnamed: D10.1 (K), R18.2
unnamed: D11.1 (K), R19.1
unnamed: J3.1, R2.1
unnamed: J3.2, R3.1
unnamed: J3.3, R4.1
unnamed: J3.4, R5.1
unnamed: J3.5, R6.1
unnamed: J3.6, J9.1, JP1.1 (A)
unnamed: J3.7, J9.3, JP2.1 (A)
unnamed: J3.8, J9.5, JP3.1 (A)
unnamed: J4.3, J6.1
unnamed: J4.4, J6.2
unnamed: J4.5, J6.3
unnamed: J4.6, J6.4
unnamed: J4.7, R17.1
unnamed: J4.8, R18.1
unnamed: J5.1, SW2.16
unnamed: J5.2, SW2.15
unnamed: J5.3, SW2.14
unnamed: J5.4, SW2.13
unnamed: J5.5, SW2.12
unnamed: J5.6, SW2.11
unnamed: J5.7, SW2.10
unnamed: J5.8, SW2.9
unnamed: J7.3, J7.5, U1.2 (-)
unnamed: J7.4, J7.6, U1.3 (+)
unnamed: J9.2, JP1.2 (B), R7.1
unnamed: J9.4, JP2.2 (B), R8.1
unnamed: J9.6, JP3.2 (B), R9.1
unnamed: Q1.2 (G), R21.2
unnamed: Q1.3 (D), R19.2
unnamed: R1.1, R2.2, R10.1
unnamed: R3.2, R10.2, R11.1
unnamed: R4.2, R11.2, R12.1
unnamed: R5.2, R12.2, R13.1
unnamed: R6.2, R13.2, R14.1
unnamed: R7.2, R14.2, R15.1
unnamed: R8.2, R15.2, R16.1
unnamed: R23.2, SW1.2

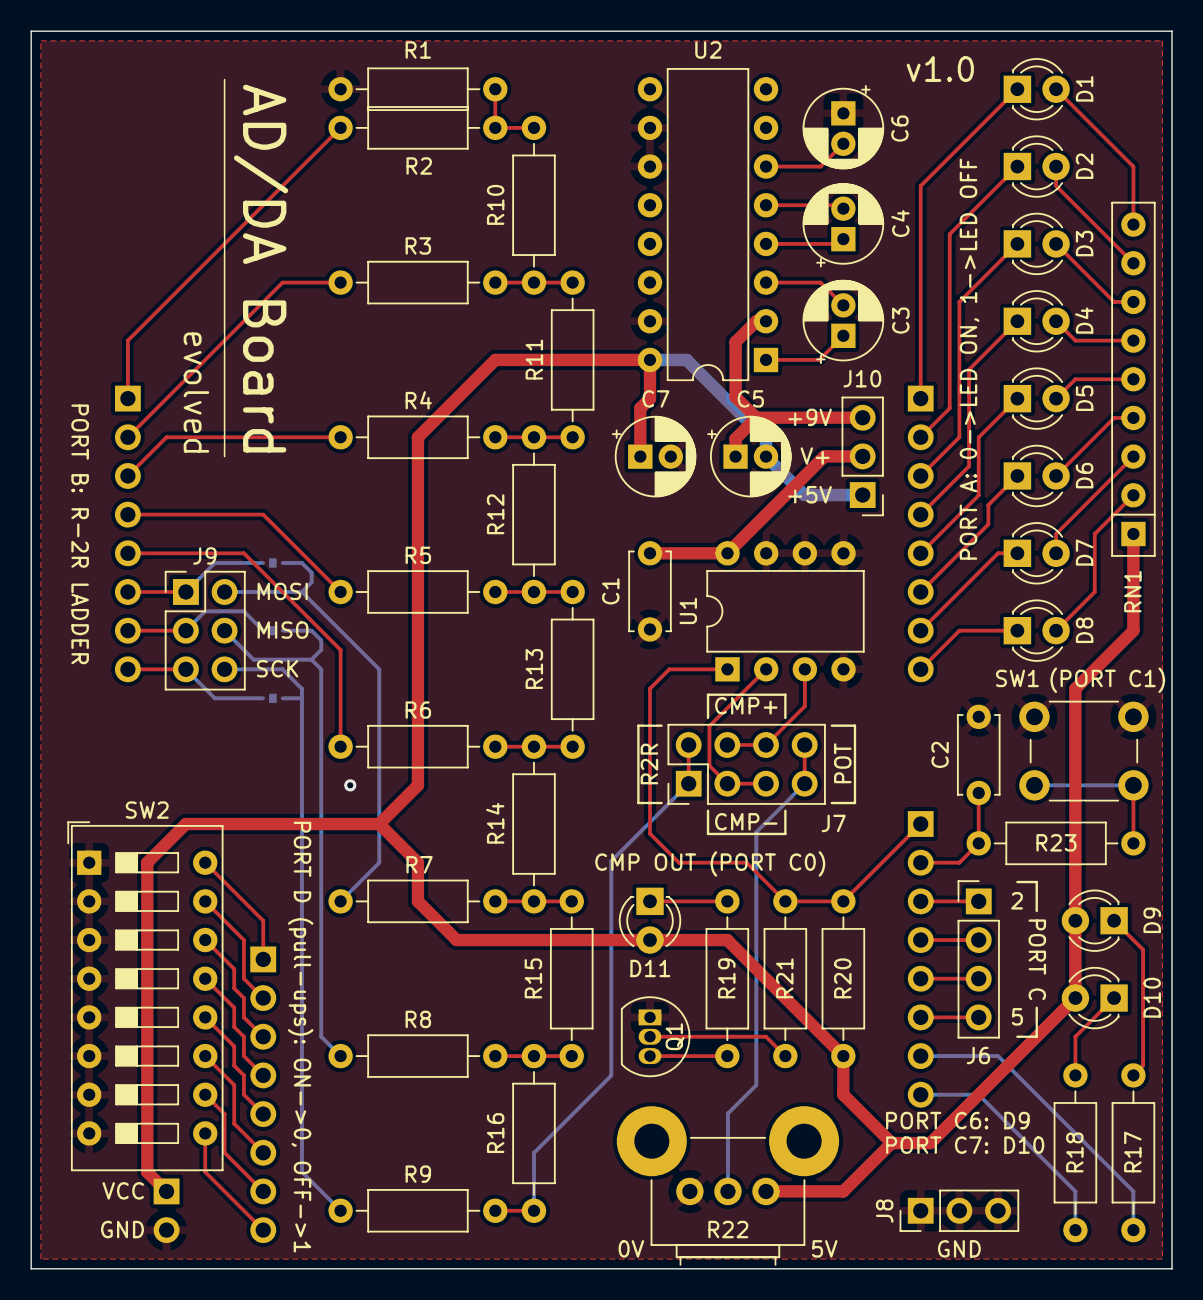
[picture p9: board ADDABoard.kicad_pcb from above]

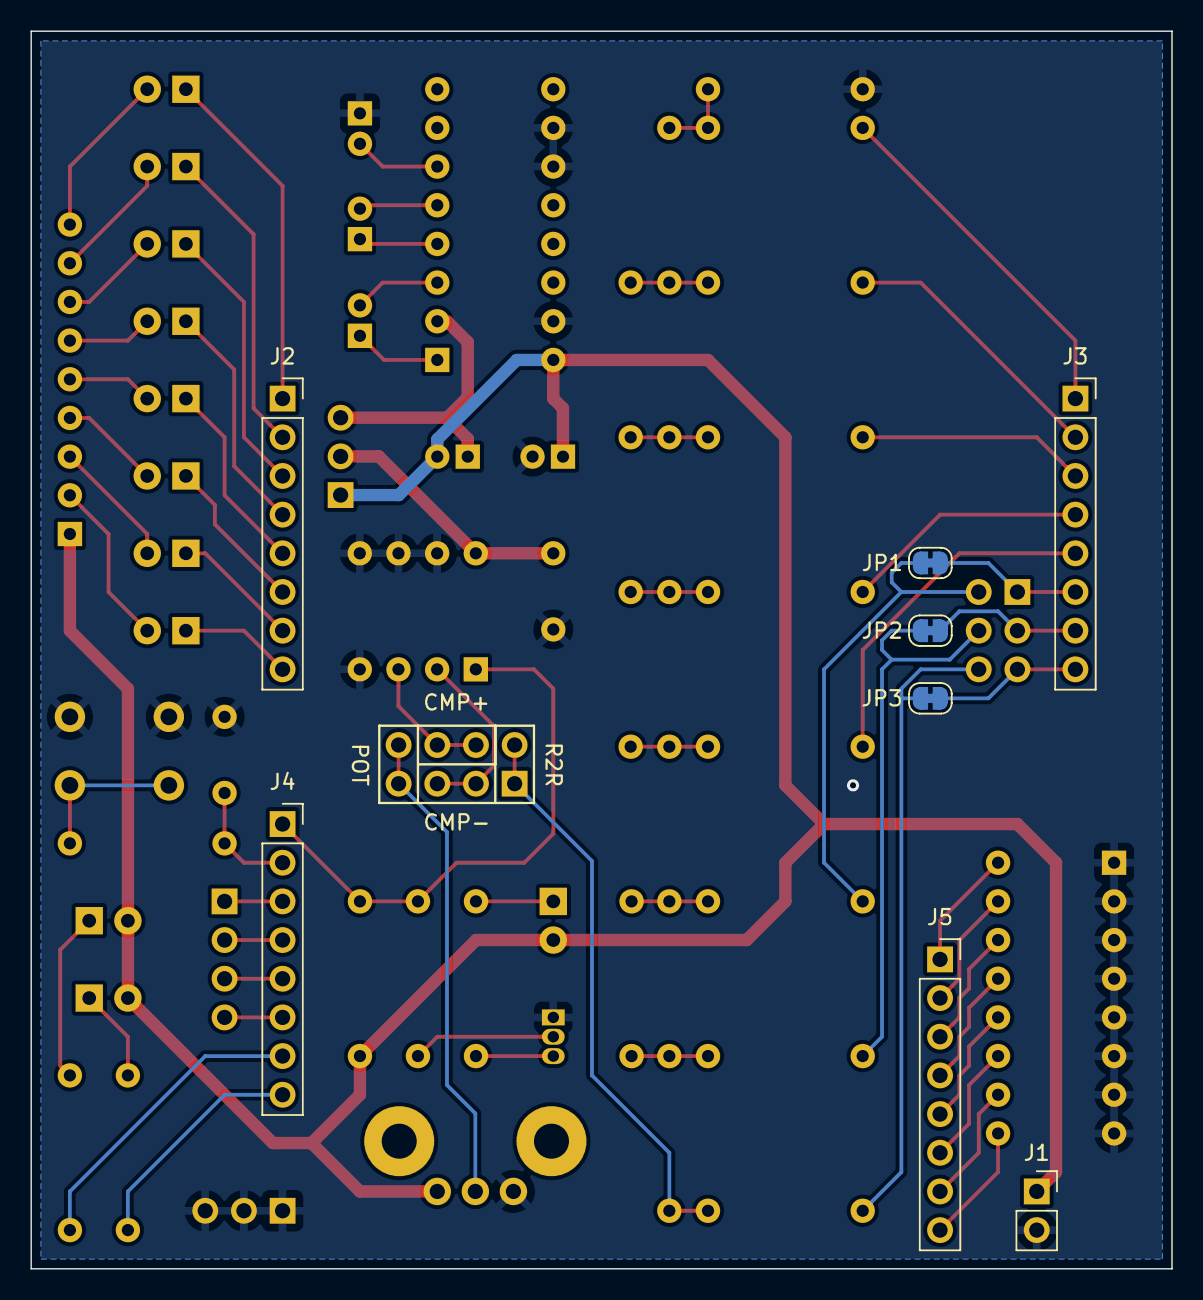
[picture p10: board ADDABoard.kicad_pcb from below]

Board: 2 copper layers, 74.9 x 81.3 mm, 60 parts (8 on the bottom side), 69 nets.

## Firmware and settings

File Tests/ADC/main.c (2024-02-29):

/*
 * A primitive ADC
 *
 * Connect R-2R to CMP+ and POT to CMP- by placing two jumpers on J7. 
 */

#include<avr/io.h>
#include<util/delay.h>

void main(void)
{
	// Configure Port A as output high
	PORTA = 0xff;
	DDRA = 0xff;
	// Configure Port B as output low
	PORTB = 0;
	DDRB = 0xff;
	// Configure Port C0 as input without pull-up
	PORTC = 0;
	DDRC = 0;

	uint8_t val = 0;
	do
	{
		// Set R-2R output
		PORTB = val;

		// Show current value via LEDs
		PORTA = ~val;

		// Stop when the analogue voltage generated from val is greater than the
		// measured voltage
		if(PINC & 1)
			break;

		val++;
		_delay_ms(100);
	}
	while(val);
	while(1);
}

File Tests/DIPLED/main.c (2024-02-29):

/*
 * Testing the LEDs and the DIP switches on the AD/DA add-on board
 */

#include<avr/io.h>

void main(void)
{
	// Configure Port A as output high
	PORTA = 0xff;
	DDRA = 0xff;
	// Configure Port D as input with pull-ups
	PORTD = 0xff;
	DDRD = 0;
	// Configure Port C1 as input with pull-up (SW1),
	// C6 as output low (LED9), and C7 as output high (LED10)
	PORTC = 0x82;
	DDRC = 0xc0;

	uint8_t sw1 = PINC & 2;
	while(1)
	{
		// Show state of DIP switches on LEDs 1..8
		PORTA = PIND;

		// If SW1 was pressed, flip LEDs 9/10
		if(sw1 && !(PINC & 2))
			PORTC ^= 0xc0;
		sw1 = PINC & 2;
	}
}
